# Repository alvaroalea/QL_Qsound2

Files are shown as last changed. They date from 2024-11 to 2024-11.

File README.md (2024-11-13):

# Sinclair QL Qsound2+
## Soundcard compatible with QsoundQprint for Sinclair QL

WARNING!!!  Actually there is a problem with this design and is not Fully Compatible with QSound, still need to do more test, music sound at half frecuency, so it's out of tune, and probably effects will be diferents.

(C) 2024 Alvaro Alea Fernandez

License under: CERN Open Hardware Licence Version 2 - Strongly Reciprocal

https://ohwr.org/cern_ohl_s_v2.txt

I upgrade the original desing:

- Using a YM2203, compatible with AY-3-8910 but add a FM sound Chanel
- Add a second way to access the chip, without the PIA (MC6821) to speedup the access.
- Fixed 2Mhz clock, same that Atari ST
- Stereo Output (ABC or ACB selectable by jumpers)

- Remain compatible with Qsound (include a jumper to select internal clock reference as in Qsound)

You can use a 2764 eprom or a W27C512 flash, that is much more cheap and easy to use.

Refer to the original repository for more information about Qsound: https://github.com/alvaroalea/QL_QsoundQprint_clone

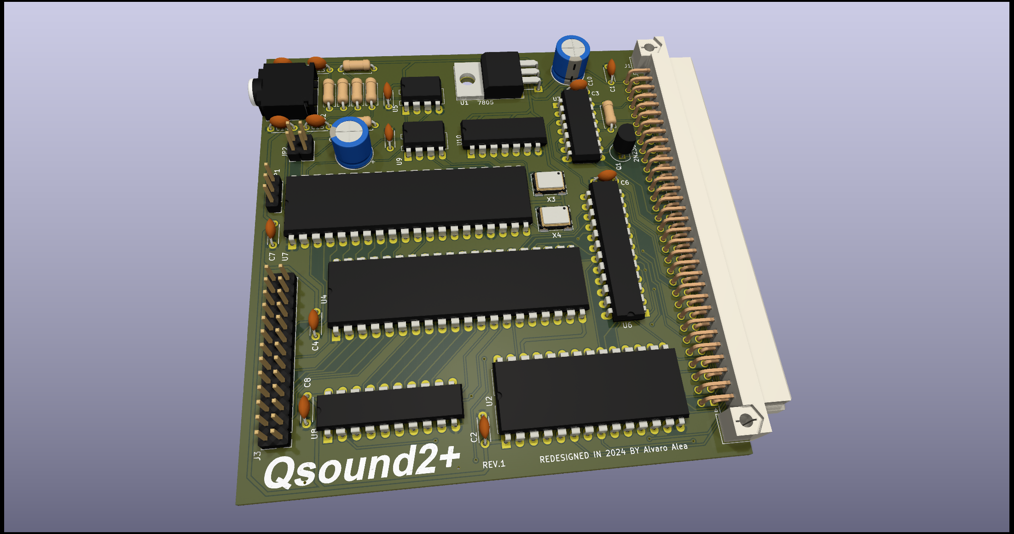
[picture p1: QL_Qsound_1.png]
 

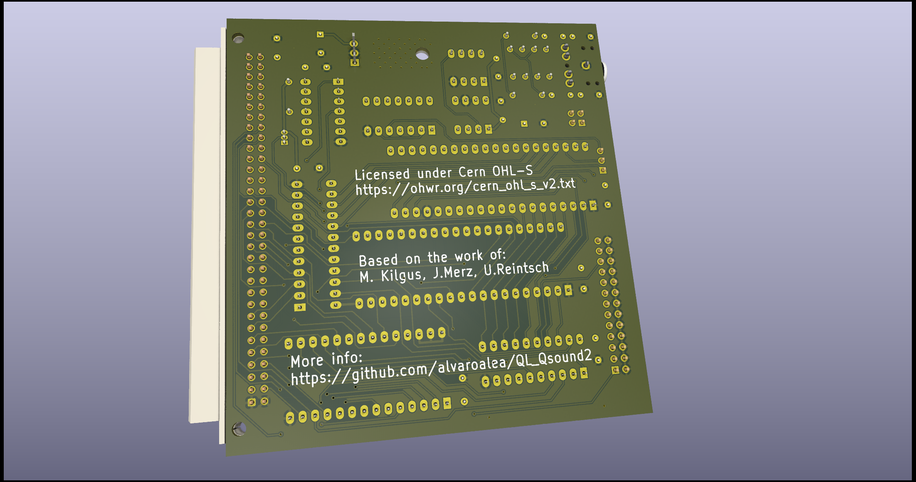
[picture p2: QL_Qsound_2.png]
 

## Technical details:
The Card reserve 16Kb of Memory space following Sinclair's P'N'P Way, this mean that is not compatible with 768Kb Trump Card, and that in most of the QL will end on the 0xC0000 - 0xC3FFFF.

The first 8Kb are occuped by the ROM

The next  4Kb are occuped by the MC6821 like in normal QSound

The last 4Kb are used for direct access to the YM2203, it use also A1, so there are two directions:

Write 0xC3000 ->  Write Address Register

Read  0xC3000 -> Read Status

Write 0xC3002 -> Write Register Value

Read  0xC3002 -> Read Register Value

There is no way to know which Clock is selected or Stereo type, this is handmade selections.

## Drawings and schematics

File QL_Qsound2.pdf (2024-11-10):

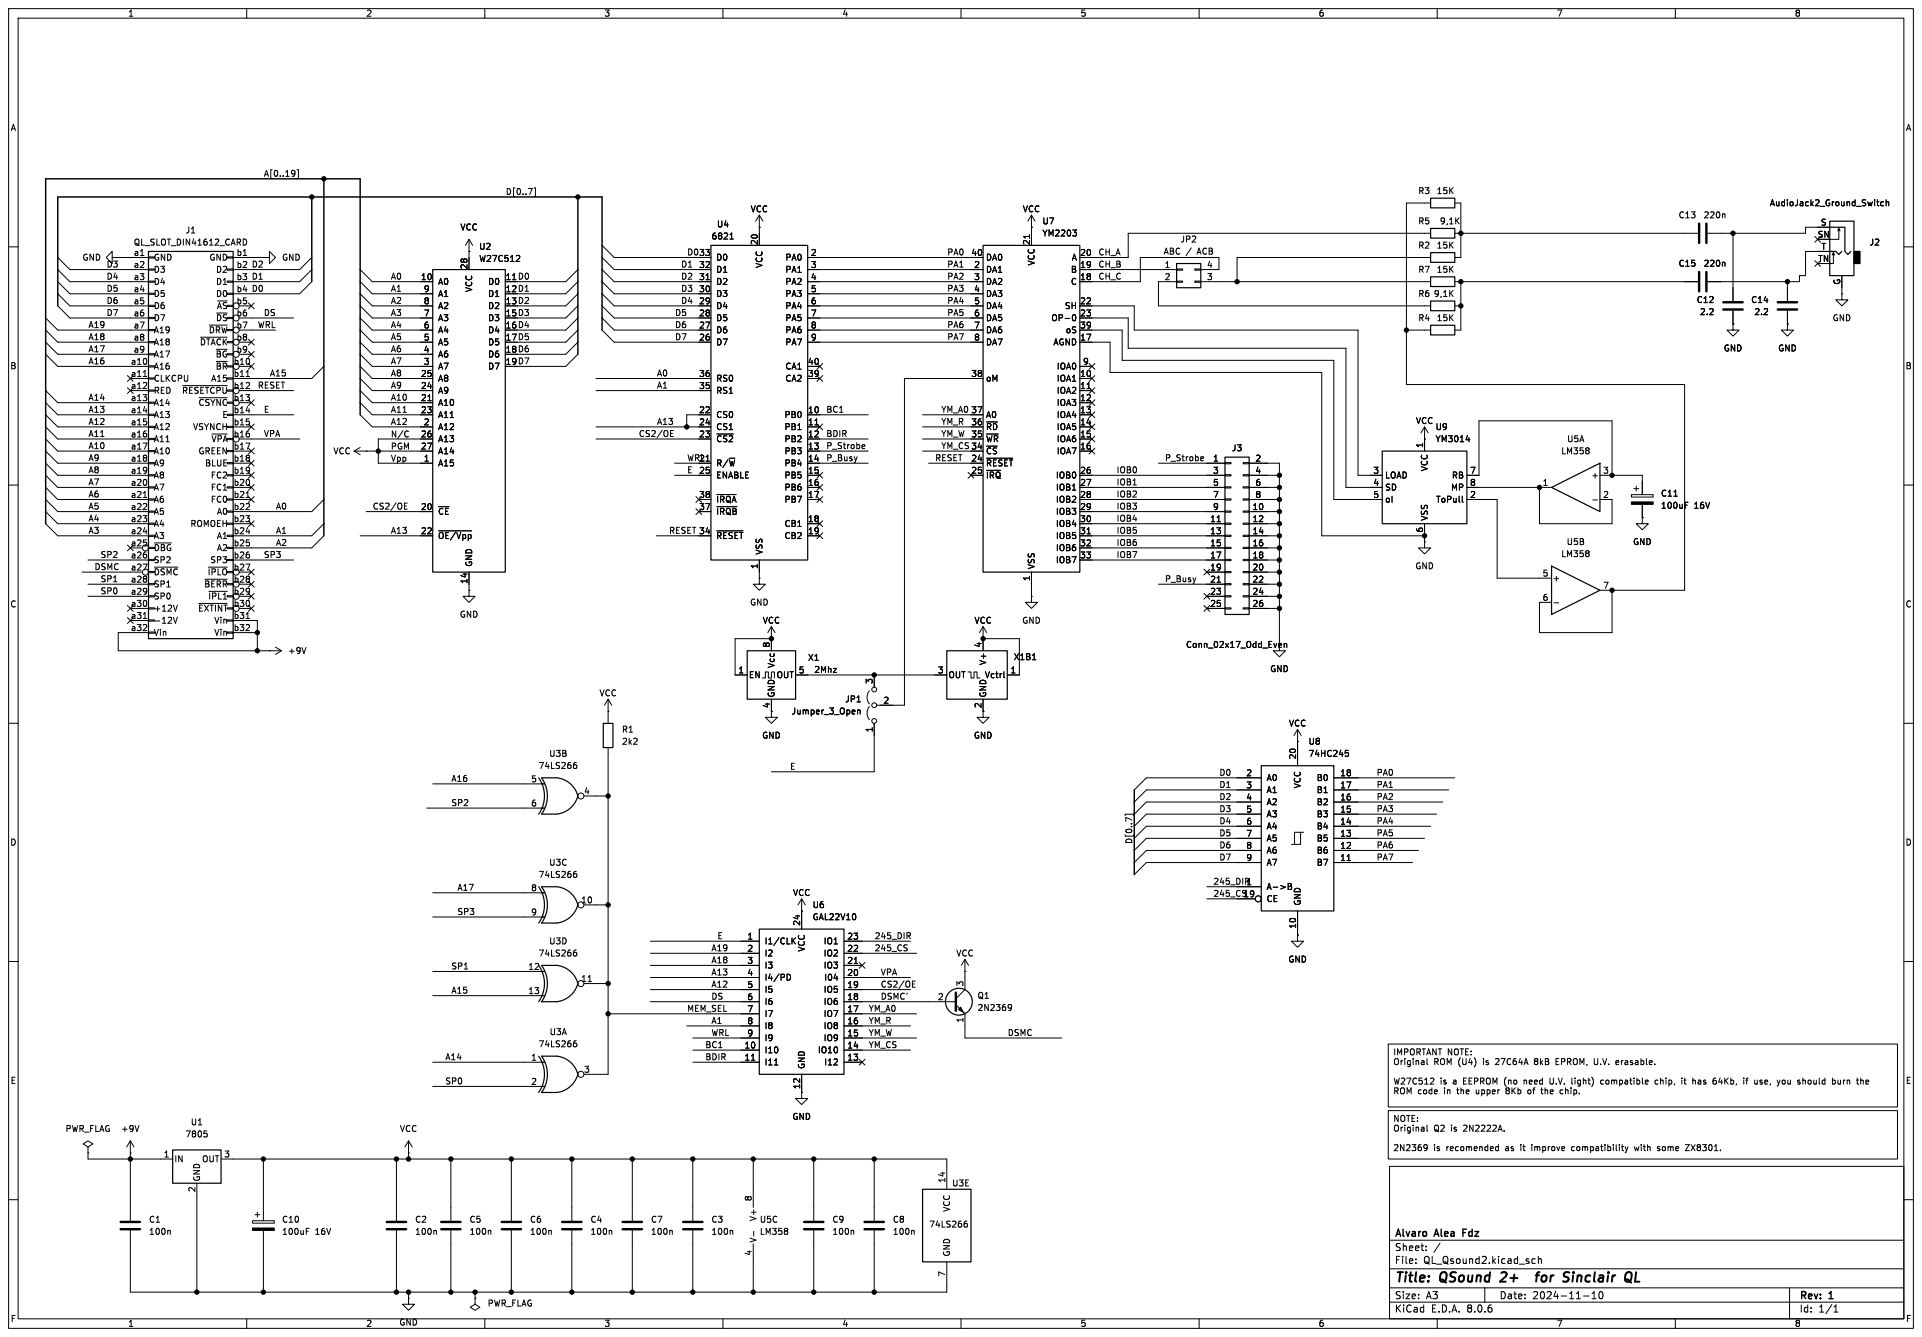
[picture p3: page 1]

b14 VSYNCH b15 ~{VPA}b16 GREEN b17 BLUE b18 FC2 b19 D2 b2 FC1 b20 FC0 b21 A0 b22 ROMOEH b23 A1 b24 A2 b25 SP3 b26 ~{IPLO}b27 ~{BERR}b28 ~{IPL1}b29 D1 b3 ~{EXTINT}b30 Vin b31 Vin b32 D0 b4 ~{AS}b5 ~{DS}b6 ~{DRW}b7 ~{DTACK}b8 ~{BG}b9

J1 QL_SLOT_DIN41612_CARD
JP2 ABC / ACB GND a1 A16 a10 CLKCPU a11 RED a12 A14 a13 A13 a14 A12 a15 A11 a16 A10 a17 A9 a18 A8 a19 D3 a2 A7 a20 A6 a21 A5 a22 A4 a23 A3 a24 ~{DBG} a25 SP2 a26 ~{DSMC} a27 SP1 a28 SP0 a29 D4 a3 +12V a30

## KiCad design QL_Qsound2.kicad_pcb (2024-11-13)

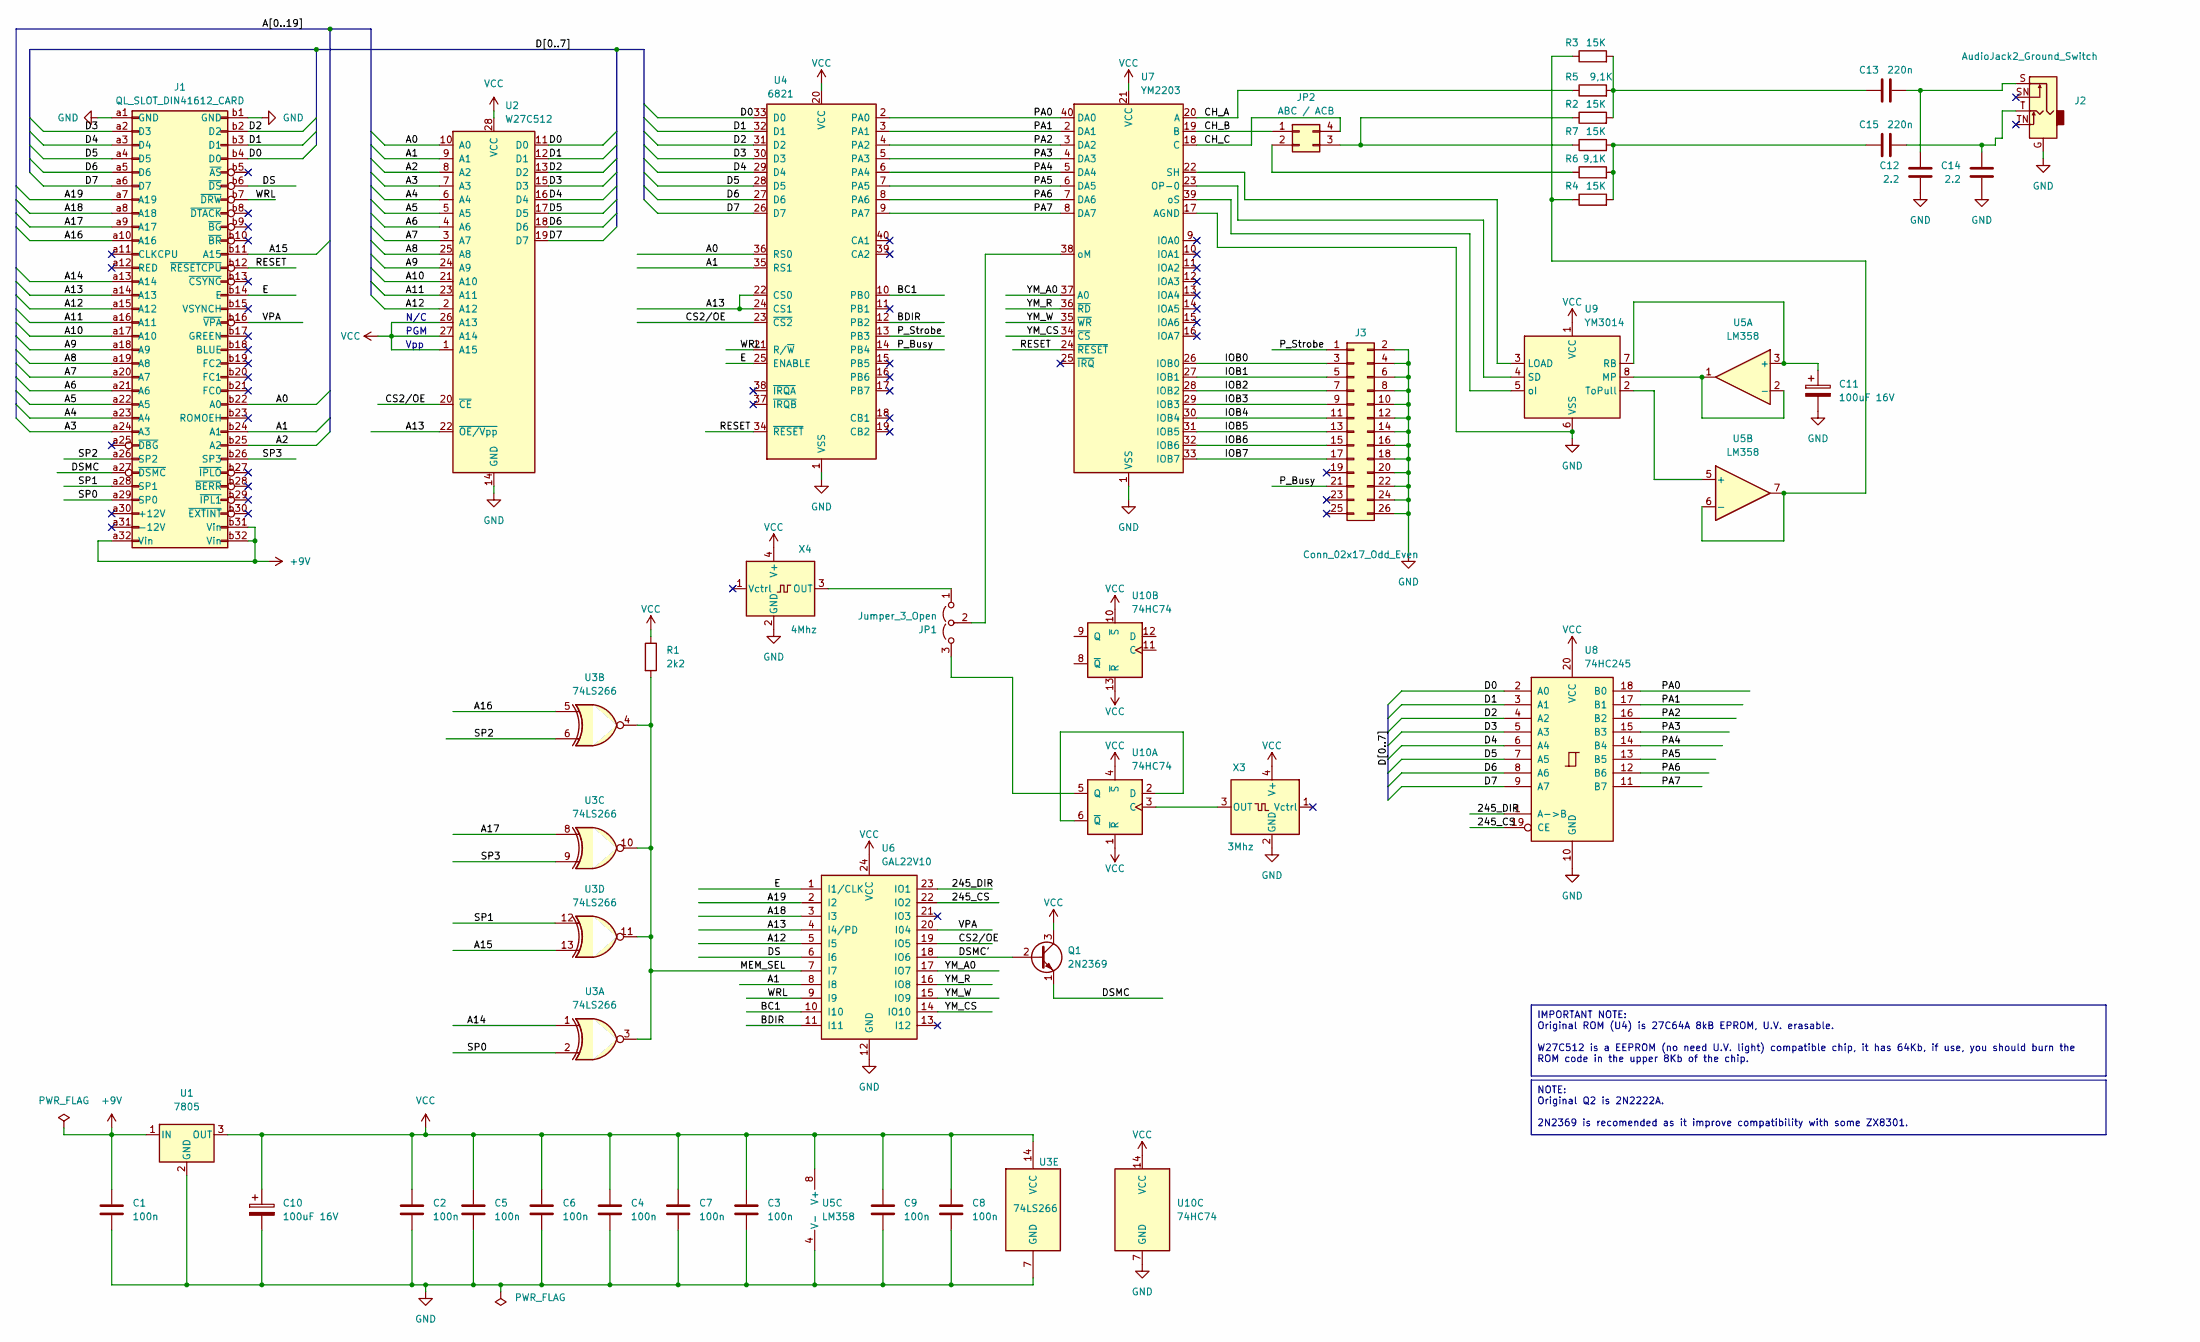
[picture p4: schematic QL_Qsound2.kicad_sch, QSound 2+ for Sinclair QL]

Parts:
C1, C2, C3, C4, C5, C6, C7, C8, C9: 100n; C_Disc_D4.3mm_W1.9mm_P5.00mm
C10, C11: 100uF 16V; CP_Radial_D8.0mm_P5.00mm
C12, C14: 2.2; C_Disc_D4.3mm_W1.9mm_P5.00mm
C13, C15: 220n; C_Disc_D4.3mm_W1.9mm_P5.00mm
J1: QL_SLOT_DIN41612_CARD; DIN41612_B_2x32_Female_Horizontal_THT
J2: AudioJack2_Ground_Switch
J3: Conn_02x17_Odd_Even; PinHeader_2x13_P2.54mm_Vertical
JP1: Jumper_3_Open; PinHeader_1x03_P2.54mm_Vertical
JP2: ABC / ACB; PinHeader_2x02_P2.54mm_Vertical
Q1: 2N2369; TO-92_Inline
R1: 2k2; R_Axial_DIN0207_L6.3mm_D2.5mm_P7.62mm_Horizontal
R2, R3, R4, R7: 15K; R_Axial_DIN0207_L6.3mm_D2.5mm_P7.62mm_Horizontal
R5, R6: 9,1K; R_Axial_DIN0207_L6.3mm_D2.5mm_P7.62mm_Horizontal
U1: 7805; TO-220-3_Horizontal_TabDown
U2: W27C512; DIP-28_W15.24mm_LongPads
U3: 74LS266; DIP-14_W7.62mm_LongPads
U4: 6821; DIP-40_W15.24mm_LongPads
U5: LM358; DIP-8_W7.62mm_LongPads
U6: GAL22V10; DIP-24_W7.62mm_LongPads
U7: YM2203; DIP-40_W15.24mm_LongPads
U8: 74HC245; DIP-20_W7.62mm_LongPads
U9: YM3014; DIP-8_W7.62mm_LongPads
U10: 74HC74; DIP-14_W7.62mm_LongPads
X3: 3Mhz; Oscillator_SMD_Abracon_ASV-4Pin_7.0x5.1mm
X4: 4Mhz; Oscillator_SMD_Abracon_ASV-4Pin_7.0x5.1mm

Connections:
+9V: C1.1, J1.a32 (Vin), J1.b31 (Vin), J1.b32 (Vin), U1.1 (IN)
/245_CS: U6.22 (IO2), U8.19 (CE)
/245_DIR: U6.23 (IO1), U8.1 (A->B)
/A0: J1.b22 (A0), U2.10 (A0), U4.36 (RS0)
/A1: J1.b24 (A1), U2.9 (A1), U4.35 (RS1), U6.8 (I8)
/A2: J1.b25 (A2), U2.8 (A2)
/A3: J1.a24 (A3), U2.7 (A3)
/A4: J1.a23 (A4), U2.6 (A4)
/A5: J1.a22 (A5), U2.5 (A5)
/A6: J1.a21 (A6), U2.4 (A6)
/A7: J1.a20 (A7), U2.3 (A7)
/A8: J1.a19 (A8), U2.25 (A8)
/A9: J1.a18 (A9), U2.24 (A9)
/A10: J1.a17 (A10), U2.21 (A10)
/A11: J1.a16 (A11), U2.23 (A11)
/A12: J1.a15 (A12), U2.2 (A12), U6.5 (I5)
/A13: J1.a14 (A13), U2.22 (~OE/Vpp), U4.22 (CS0), U4.24 (CS1), U6.4 (I4/PD)
/A14: J1.a13 (A14), U3.1
/A15: J1.b11 (A15), U3.13
/A16: J1.a10 (A16), U3.5
/A17: J1.a9 (A17), U3.8
/A18: J1.a8 (A18), U6.3 (I3)
/A19: J1.a7 (A19), U6.2 (I2)
/BC1: U4.10 (PB0), U6.10 (I10)
/BDIR: U4.12 (PB2), U6.11 (I11)
/CH_A: R5.1, U7.20 (A)
/CH_B: JP2.1, U7.19 (B)
/CH_C: JP2.4, U7.18 (C)
/CS2/OE: U2.20 (~CE), U4.23 (~CS2), U6.19 (IO5)
/D0: J1.b4 (D0), U2.11 (D0), U4.33 (D0), U8.2 (A0)
/D1: J1.b3 (D1), U2.12 (D1), U4.32 (D1), U8.3 (A1)
/D2: J1.b2 (D2), U2.13 (D2), U4.31 (D2), U8.4 (A2)
/D3: J1.a2 (D3), U2.15 (D3), U4.30 (D3), U8.5 (A3)
/D4: J1.a3 (D4), U2.16 (D4), U4.29 (D4), U8.6 (A4)
/D5: J1.a4 (D5), U2.17 (D5), U4.28 (D5), U8.7 (A5)
/D6: J1.a5 (D6), U2.18 (D6), U4.27 (D6), U8.8 (A6)
/D7: J1.a6 (D7), U2.19 (D7), U4.26 (D7), U8.9 (A7)
/DS: J1.b6 (~DS), U6.6 (I6)
/DSMC: J1.a27 (~DSMC), Q1.1 (E)
/DSMC': Q1.2 (B), U6.18 (IO6)
/E: J1.b14 (E), U4.25 (ENABLE), U6.1 (I1/CLK)
/IOB0: J3.3, U7.26 (IOB0)
/IOB1: J3.5, U7.27 (IOB1)
/IOB2: J3.7, U7.28 (IOB2)
/IOB3: J3.9, U7.29 (IOB3)
/IOB4: J3.11, U7.30 (IOB4)
/IOB5: J3.13, U7.31 (IOB5)
/IOB6: J3.15, U7.32 (IOB6)
/IOB7: J3.17, U7.33 (IOB7)
/MEM_SEL: R1.2, U3.3, U3.4, U3.10, U3.11, U6.7 (I7)
/PA0: U4.2 (PA0), U7.40 (DA0), U8.18 (B0)
/PA1: U4.3 (PA1), U7.2 (DA1), U8.17 (B1)
/PA2: U4.4 (PA2), U7.3 (DA2), U8.16 (B2)
/PA3: U4.5 (PA3), U7.4 (DA3), U8.15 (B3)
/PA4: U4.6 (PA4), U7.5 (DA4), U8.14 (B4)
/PA5: U4.7 (PA5), U7.6 (DA5), U8.13 (B5)
/PA6: U4.8 (PA6), U7.7 (DA6), U8.12 (B6)
/PA7: U4.9 (PA7), U7.8 (DA7), U8.11 (B7)
/P_Busy: J3.21, U4.14 (PB4)
/P_Strobe: J3.1, U4.13 (PB3)
/RESET: J1.b12 (~RESETCPU), U4.34 (~RESET), U7.24 (~RESET)
/SP0: J1.a29 (SP0), U3.2
/SP1: J1.a28 (SP1), U3.12
/SP2: J1.a26 (SP2), U3.6
/SP3: J1.b26 (SP3), U3.9
/VPA: J1.b16 (~VPA), U6.20 (I04)
/WRL: J1.b7 (~DRW), U4.21 (R/~W), U6.9 (I9)
/YM_A0: U6.17 (IO7), U7.37 (A0)
/YM_CS: U6.14 (IO10), U7.34 (~CS)
/YM_R: U6.16 (IO8), U7.36 (~RD)
/YM_W: U6.15 (IO9), U7.35 (~WR)
GND: C1.2, C2.2, C3.2, C4.2, C5.2, C6.2, C7.2, C8.2, C9.2, C10.2, C11.2, C12.2, C14.2, J1.a1 (GND), J1.b1 (GND), J2.G, J3.2, J3.4, J3.6, J3.8, J3.10, J3.12, J3.14, J3.16, J3.18, J3.20, J3.22, J3.24, J3.26, U1.2 (GND), U2.14 (GND), U3.7 (GND), U4.1 (VSS), U5.4 (V-), U6.12 (GND), U7.1 (VSS), U7.17 (AGND), U8.10 (GND), U9.6 (VSS), U10.7 (GND), X3.2 (GND), X4.2 (GND)
unnamed: C12.1, C13.2, J2.S
unnamed: C13.1, R2.2, R3.2, R5.2
unnamed: C14.1, C15.2, J2.T
unnamed: C15.1, R4.2, R6.2, R7.2
unnamed: JP1.1 (A), X4.3 (OUT)
unnamed: JP1.3 (B), U10.5 (Q)
unnamed: JP1.2 (C), U7.38 (oM)
unnamed: JP2.2, R6.1
unnamed: JP2.3, R2.1, R7.1
unnamed: C11.1, U5.3 (+), U9.7 (RB)
unnamed: U5.1, U5.2 (-), U9.8 (MP)
unnamed: U5.5 (+), U9.2 (ToPull)
unnamed: R3.1, R4.1, U5.6 (-), U5.7
unnamed: U7.23 (OP-0), U9.4 (SD)
unnamed: U7.22 (SH), U9.3 (LOAD)
unnamed: U7.39 (oS), U9.5 (oI)
unnamed: U10.3 (C), X3.3 (OUT)
unnamed: U10.2 (D), U10.6 (~Q)
VCC: C2.1, C3.1, C4.1, C5.1, C6.1, C7.1, C8.1, C9.1, C10.1, Q1.3 (C), R1.1, U1.3 (OUT), U2.1 (A15), U2.26 (A13), U2.27 (A14), U2.28 (VCC), U3.14 (VCC), U4.20 (VCC), U5.8 (V+), U6.24 (VCC), U7.21 (VCC), U8.20 (VCC), U9.1 (VCC), U10.1 (~R), U10.4 (~S), U10.10 (~S), U10.13 (~R), U10.14 (VCC), X3.4 (V+), X4.4 (V+)

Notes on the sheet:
NOTE: Original Q2 is 2N2222A. 2N2369 is recomended as it improve compatibility with some ZX8301.
IMPORTANT NOTE: Original ROM (U4) is 27C64A 8kB EPROM, U.V. erasable. W27C512 is a EEPROM (no need U.V. light) compatible chip, it has 64Kb, if use, you should burn the ROM code in the upper 8Kb of the chip.
Vpp
N/C
PGM

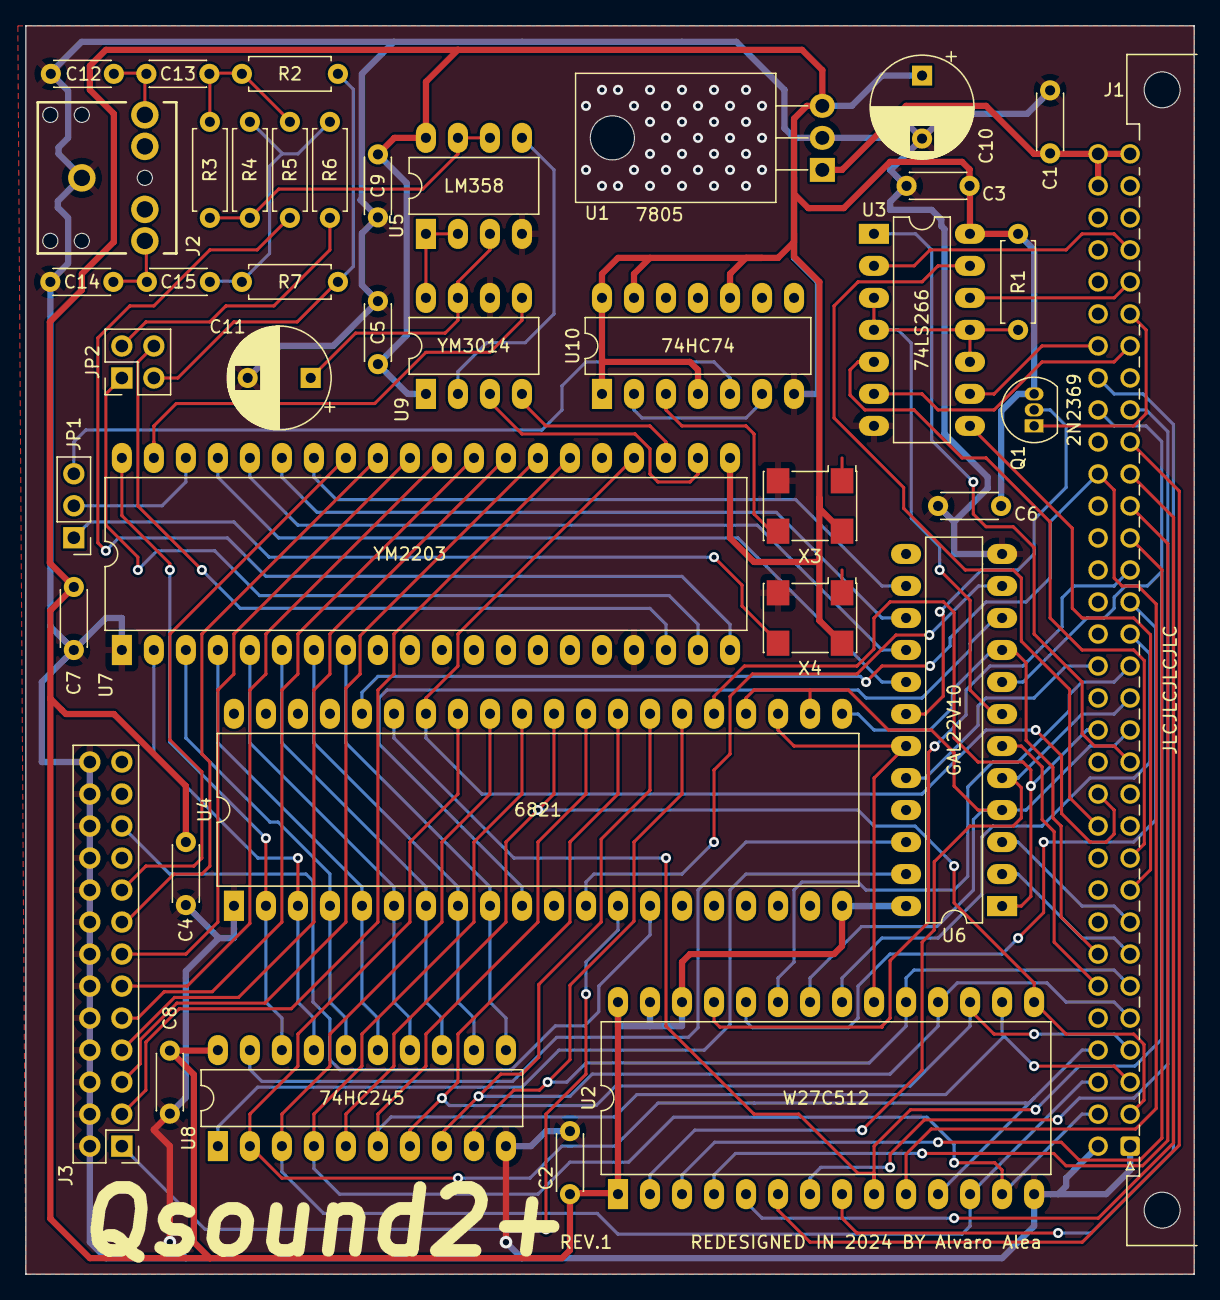
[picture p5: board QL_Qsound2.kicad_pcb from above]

Board: 2 copper layers, 92.7 x 99.1 mm, 40 parts (0 on the bottom side), 91 nets.

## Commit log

2024-11-11 ADD NOTE
    [QL_Qsound2-B_Cu.gbr, QL_Qsound2-B_Mask.gbr, QL_Qsound2-B_Silks.gbr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]
2024-11-13 new clock oscilators
    [QL_Qsound2-B_Cu.gbr, QL_Qsound2-B_Mask.gbr, QL_Qsound2-B_Silks.gbr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]

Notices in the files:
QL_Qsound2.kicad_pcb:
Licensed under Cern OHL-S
